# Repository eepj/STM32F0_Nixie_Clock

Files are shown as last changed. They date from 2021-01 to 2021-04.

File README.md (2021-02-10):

# STM32F0_Nixie_Clock
An STM32 nixie clock project.

## Disclaimer
High DC voltages can cause severe injuries or death. Proceed at your own risk.

## Hardware 
### Files
* [KiCad project](./Hardware/STM32F0_Nixie_Clock.pro)
* [Schematics](./Hardware/STM32F0_Nixie_Clock.pdf)
* [Gerber](./main/Hardware/Gerber)

### Parts
Refer to [BOM](./Hardware/STM32F0_Nixie_Clock_BOM.xlsx):
* [STM32F042F6 core](https://www.st.com/resource/en/datasheet/stm32f042f6.pdf)
* [MAX1771 step-up driver](https://datasheets.maximintegrated.com/en/ds/MAX1771.pdf)
* [DS3231 I2C RTC](https://www.maximintegrated.com/en/products/analog/real-time-clocks/DS3231.html)
* [HV5222 32-channel open-drain serial-to-parallel converter](https://ww1.microchip.com/downloads/en/DeviceDoc/20005418B.pdf)

## Firmware
### Programs
* Main program: [`main.c`](./Firmware/Core/Src/main.c)
* Interrupts: [`stm32f0xx_it.c`](/Firmware/Core/Src/stm32f0xx_it.c)

### Custom libraries
* HV5222 driver: [`nixie.h`](./Firmware/Core/Src/lib/sr)
* DS3231 driver: [`ds3231_for_stm32_hal.h`](https://github.com/eepj/ds3231_for_stm32_hal)

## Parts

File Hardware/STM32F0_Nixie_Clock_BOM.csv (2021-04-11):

Designator | Value | Footprint
BT101 | CR2032 3V | Battery:BatteryHolder_Keystone_1060_1x2032
C101 | 2.2u | Capacitor_SMD:C_0603_1608Metric_Pad1.05x0.95mm_HandSolder
C102 | 100n | Capacitor_SMD:C_0603_1608Metric_Pad1.05x0.95mm_HandSolder
C103 | 1u | Capacitor_SMD:C_1206_3216Metric_Pad1.42x1.75mm_HandSolder
C104 | 4.7u | Capacitor_SMD:C_1210_3225Metric_Pad1.42x2.65mm_HandSolder
C105 | 4.7u/400V | Capacitor_SMD:CP_Elec_8x10.5
C106 | 220u/16V | Capacitor_SMD:CP_Elec_6.3x7.7
C107 | 100n | Capacitor_SMD:C_0603_1608Metric_Pad1.05x0.95mm_HandSolder
C108 | 100n | Capacitor_SMD:C_0603_1608Metric_Pad1.05x0.95mm_HandSolder
D101 | ES2J | Diode_SMD:D_SMA_Handsoldering
DS101 | JST PH 2.0mm 11P | Connector_JST:JST_PH_B11B-PH-K_1x11_P2.00mm_Vertical
DS102 | JST PH 2.0mm 11P | Connector_JST:JST_PH_B11B-PH-K_1x11_P2.00mm_Vertical
DS103 | JST PH 2.0mm 11P | Connector_JST:JST_PH_B11B-PH-K_1x11_P2.00mm_Vertical
DS104 | JST PH 2.0mm 11P | Connector_JST:JST_PH_B11B-PH-K_1x11_P2.00mm_Vertical
DS105 | JST PH 2.0mm 11P | Connector_JST:JST_PH_B11B-PH-K_1x11_P2.00mm_Vertical
DS106 | JST PH 2.0mm 11P | Connector_JST:JST_PH_B11B-PH-K_1x11_P2.00mm_Vertical
J101 | USB-C Receptacle | Connector_USB:USB_C_Receptacle_HRO_TYPE-C-31-M-12
L101 | 100u/2.2A | Inductor_SMD:L_12x12mm_H8mm
NE101 | Dot 1 | Connector_JST:JST_PH_B2B-PH-K_1x02_P2.00mm_Vertical
NE102 | Dot 2 | Connector_JST:JST_PH_B2B-PH-K_1x02_P2.00mm_Vertical
NE103 | Dot 3 | Connector_JST:JST_PH_B2B-PH-K_1x02_P2.00mm_Vertical
NE104 | Dot 4 | Connector_JST:JST_PH_B2B-PH-K_1x02_P2.00mm_Vertical
Q101 | IRF740S | Package_TO_SOT_SMD:TO-263-2
R101 | 10k | Resistor_SMD:R_0603_1608Metric_Pad1.05x0.95mm_HandSolder
R102 | 4k7 | Resistor_SMD:R_0603_1608Metric_Pad1.05x0.95mm_HandSolder
R103 | 4k7 | Resistor_SMD:R_0603_1608Metric_Pad1.05x0.95mm_HandSolder
R104 | 10k | Resistor_SMD:R_0603_1608Metric_Pad1.05x0.95mm_HandSolder
R105 | 1M1 | Resistor_SMD:R_0603_1608Metric_Pad1.05x0.95mm_HandSolder
R106 | R050 | Resistor_SMD:R_2512_6332Metric_Pad1.52x3.35mm_HandSolder
R107 | 10k | Resistor_SMD:R_0603_1608Metric_Pad1.05x0.95mm_HandSolder
R108 | 20k | Resistor_SMD:R_0603_1608Metric_Pad1.05x0.95mm_HandSolder
R109 | 20k | Resistor_SMD:R_0603_1608Metric_Pad1.05x0.95mm_HandSolder
R110 | 20k | Resistor_SMD:R_0603_1608Metric_Pad1.05x0.95mm_HandSolder
R111 | 20k | Resistor_SMD:R_0603_1608Metric_Pad1.05x0.95mm_HandSolder
R112 | 20k | Resistor_SMD:R_0603_1608Metric_Pad1.05x0.95mm_HandSolder
R113 | 20k | Resistor_SMD:R_0603_1608Metric_Pad1.05x0.95mm_HandSolder
R114 | 20k | Resistor_SMD:R_0603_1608Metric_Pad1.05x0.95mm_HandSolder
R115 | 20k | Resistor_SMD:R_0603_1608Metric_Pad1.05x0.95mm_HandSolder
R116 | 20k | Resistor_SMD:R_0603_1608Metric_Pad1.05x0.95mm_HandSolder
R117 | 20k | Resistor_SMD:R_0603_1608Metric_Pad1.05x0.95mm_HandSolder
RV101 | 200k | Potentiometer_THT:Potentiometer_Vishay_T73YP_Vertical
SW101 | TL3342 | Button_Switch_SMD:SW_SPST_TL3342
U101 | STM32F042F6P6 | Package_SO:TSSOP-20_4.4x6.5mm_P0.65mm
U102 | AMS1117-3.3 | Package_TO_SOT_SMD:SOT-223-3_TabPin2
U103 | DS3231M | Package_SO:SOIC-16W_7.5x10.3mm_P1.27mm
U104 | MAX1771 | Package_SO:SO-8_3.9x4.9mm_P1.27mm
U105 | HV5222PLCC | Package_LCC:PLCC-44_16.6x16.6mm_P1.27mm
U106 | HV5222PLCC | Package_LCC:PLCC-44_16.6x16.6mm_P1.27mm

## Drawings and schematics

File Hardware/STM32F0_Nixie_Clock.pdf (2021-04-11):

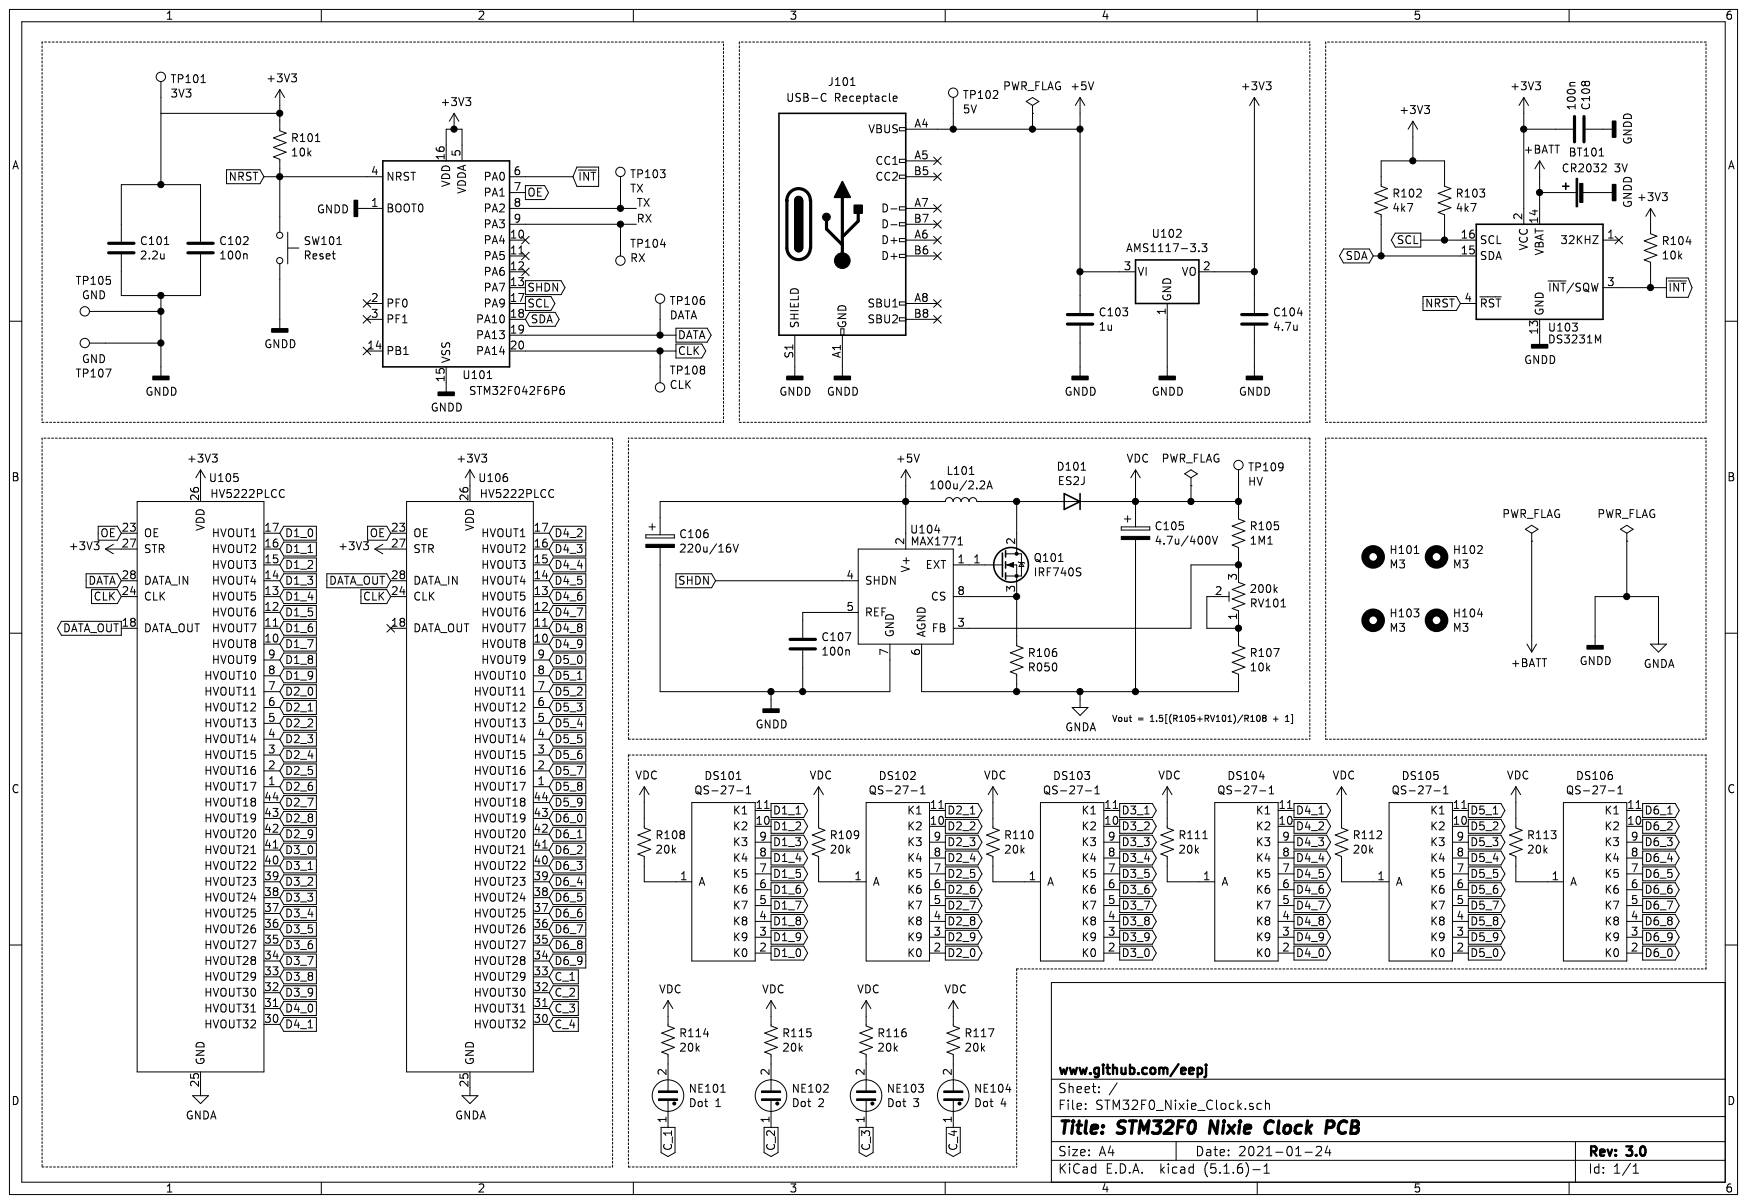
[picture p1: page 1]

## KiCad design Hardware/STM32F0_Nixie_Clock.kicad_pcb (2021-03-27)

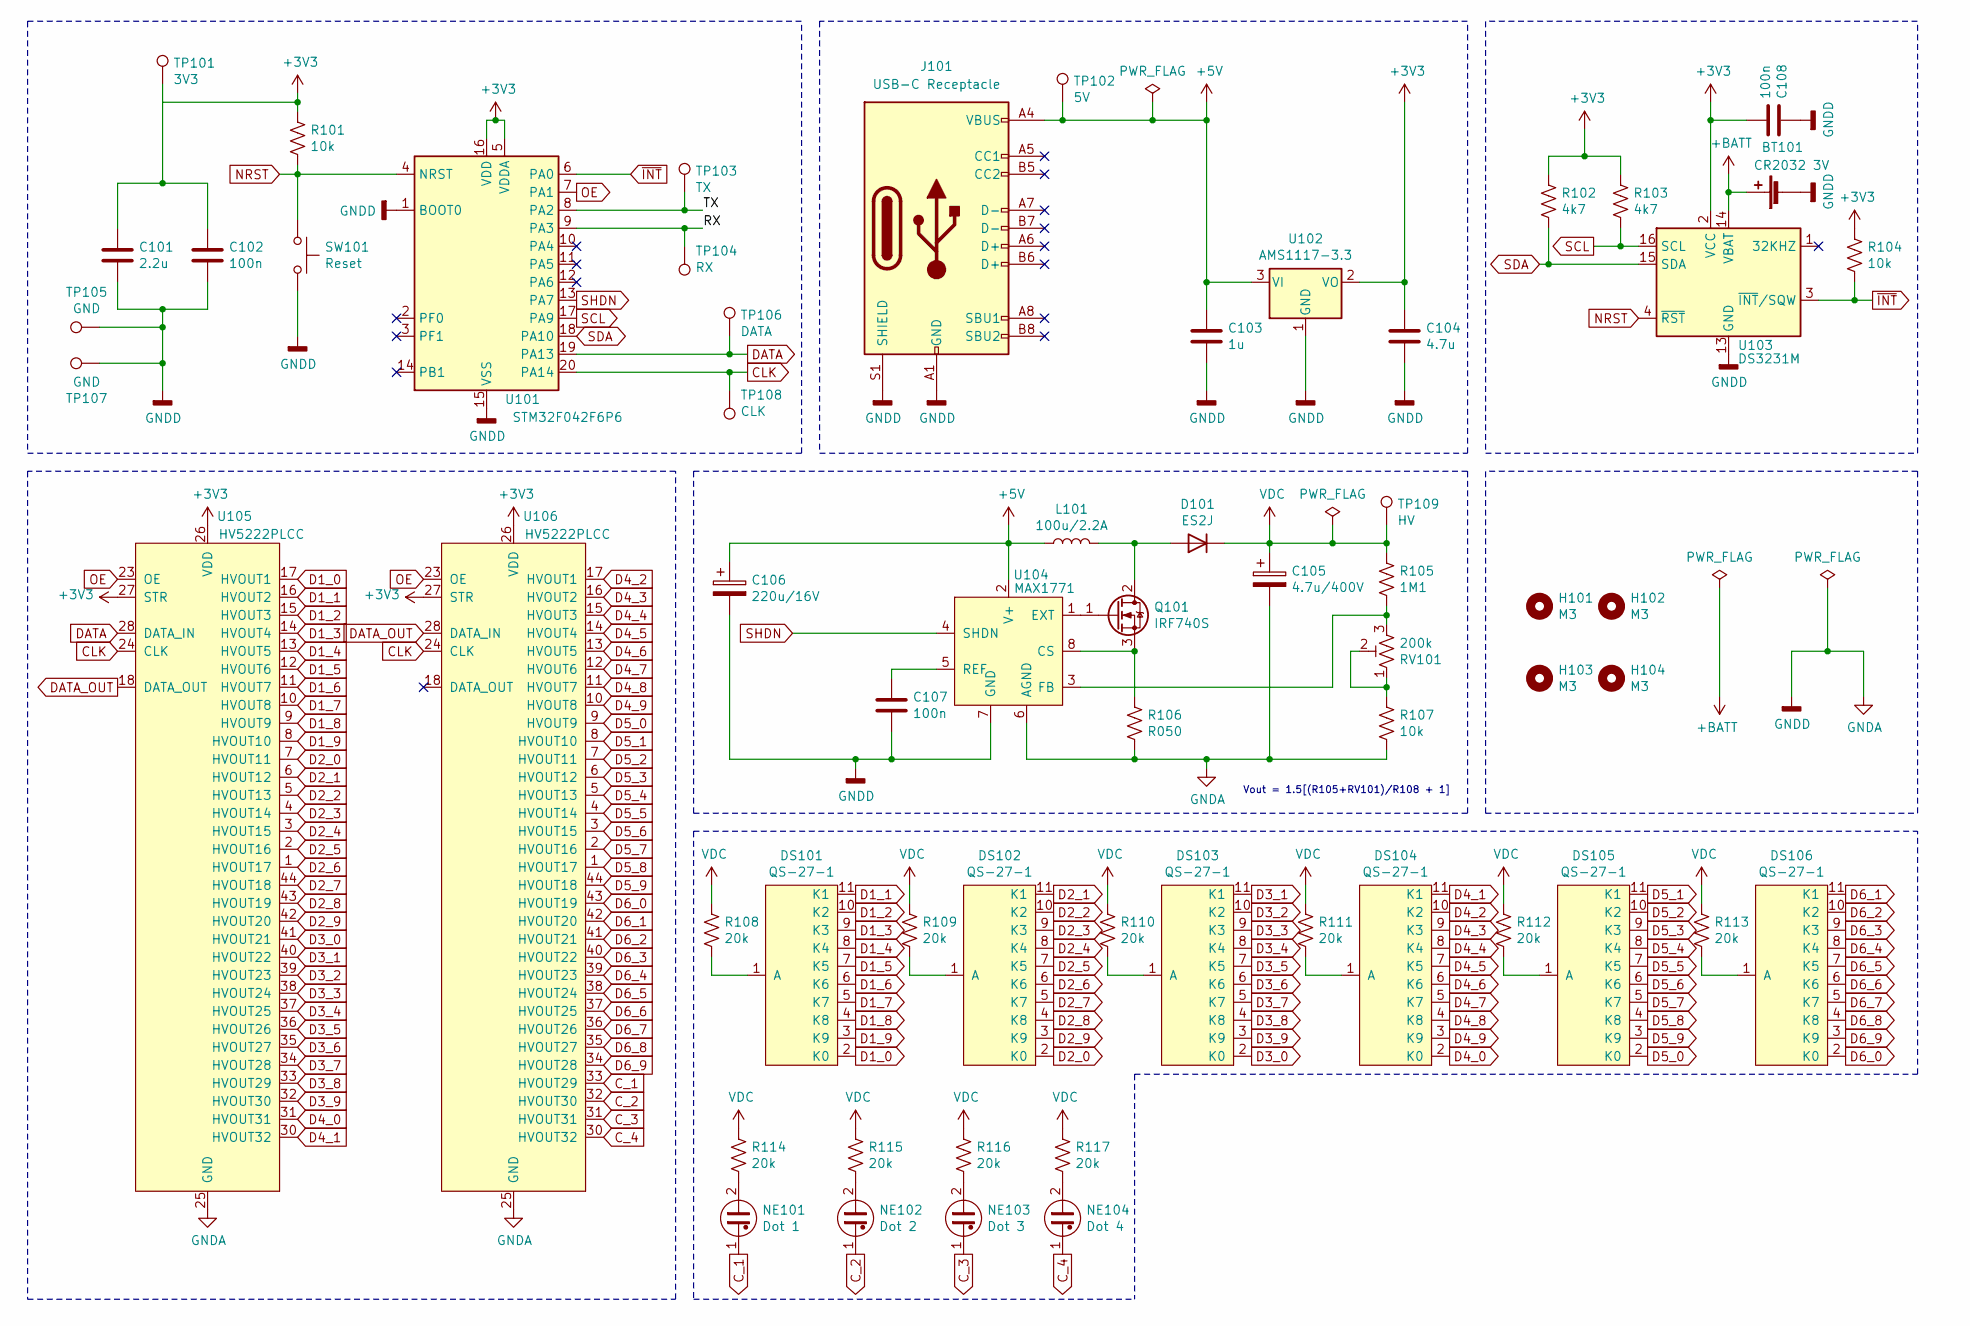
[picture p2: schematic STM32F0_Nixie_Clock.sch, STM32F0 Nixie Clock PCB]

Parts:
BT101: CR2032 3V; BatteryHolder_Keystone_1060_1x2032
C101: 2.2u; C_0603_1608Metric_Pad1.05x0.95mm_HandSolder
C102, C107, C108: 100n; C_0603_1608Metric_Pad1.05x0.95mm_HandSolder
C103: 1u; C_1206_3216Metric_Pad1.42x1.75mm_HandSolder
C104: 4.7u; C_1210_3225Metric_Pad1.42x2.65mm_HandSolder
C105: 4.7u/400V; CP_Elec_8x10.5
C106: 220u/16V; CP_Elec_6.3x7.7
D101: ES2J; D_SMA_Handsoldering
DS101, DS102, DS103, DS104, DS105, DS106: QS-27-1; JST_PH_B11B-PH-K_1x11_P2.00mm_Vertical
H101, H102, H103, H104: M3; MountingHole_3.2mm_M3
J101: USB-C Receptacle; USB_C_Receptacle_HRO_TYPE-C-31-M-12
L101: 100u/2.2A; L_12x12mm_H8mm
NE101: Dot 1; JST_PH_B2B-PH-K_1x02_P2.00mm_Vertical
NE102: Dot 2; JST_PH_B2B-PH-K_1x02_P2.00mm_Vertical
NE103: Dot 3; JST_PH_B2B-PH-K_1x02_P2.00mm_Vertical
NE104: Dot 4; JST_PH_B2B-PH-K_1x02_P2.00mm_Vertical
Q101: IRF740S; TO-263-2
R101, R104, R107: 10k; R_0603_1608Metric_Pad1.05x0.95mm_HandSolder
R102, R103: 4k7; R_0603_1608Metric_Pad1.05x0.95mm_HandSolder
R105: 1M1; R_0603_1608Metric_Pad1.05x0.95mm_HandSolder
R106: R050; R_2512_6332Metric_Pad1.52x3.35mm_HandSolder
R108, R109, R110, R111, R112, R113, R114, R115, R116, R117: 20k; R_0603_1608Metric_Pad1.05x0.95mm_HandSolder
RV101: 200k; Potentiometer_Vishay_T73YP_Vertical
SW101: Reset; SW_SPST_TL3342
TP101: 3V3; TestPoint_Pad_D1.5mm
TP102: 5V; TestPoint_Pad_D1.5mm
TP103: TX; TestPoint_Pad_D1.5mm
TP104: RX; TestPoint_Pad_D1.5mm
TP105, TP107: GND; TestPoint_Pad_D1.5mm
TP106: DATA; TestPoint_Pad_D1.5mm
TP108: CLK; TestPoint_Pad_D1.5mm
TP109: HV; TestPoint_Pad_1.0x1.0mm
U101: STM32F042F6P6; TSSOP-20_4.4x6.5mm_P0.65mm
U102: AMS1117-3.3; SOT-223-3_TabPin2
U103: DS3231M; SOIC-16W_7.5x10.3mm_P1.27mm
U104: MAX1771; SO-8_3.9x4.9mm_P1.27mm
U105, U106: HV5222PLCC; PLCC-44_16.6x16.6mm_P1.27mm

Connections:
+3V3: C101.1, C102.1, C104.1, C108.2, R101.1, R102.1, R103.1, R104.1, TP101.1, U101.5 (VDDA), U101.16 (VDD), U102.2 (VO), U103.2 (VCC), U105.26 (VDD), U105.27 (STR), U106.26 (VDD), U106.27 (STR)
+5V: C103.1, C106.1, J101.A4 (VBUS), J101.A9 (VBUS), J101.B4 (VBUS), J101.B9 (VBUS), L101.1, TP102.1, U102.3 (VI), U104.2 (V+)
+BATT: BT101.1 (+), U103.14 (VBAT)
/RX: TP104.1, U101.9 (PA3)
/TX: TP103.1, U101.8 (PA2)
CLK: TP108.1, U101.20 (PA14), U105.24 (CLK), U106.24 (CLK)
C_1: NE101.1, U106.33 (HVOUT29)
C_2: NE102.1, U106.32 (HVOUT30)
C_3: NE103.1, U106.31 (HVOUT31)
C_4: NE104.1, U106.30 (HVOUT32)
D1_0: DS101.2 (K0), U105.17 (HVOUT1)
D1_1: DS101.11 (K1), U105.16 (HVOUT2)
D1_2: DS101.10 (K2), U105.15 (HVOUT3)
D1_3: DS101.9 (K3), U105.14 (HVOUT4)
D1_4: DS101.8 (K4), U105.13 (HVOUT5)
D1_5: DS101.7 (K5), U105.12 (HVOUT6)
D1_6: DS101.6 (K6), U105.11 (HVOUT7)
D1_7: DS101.5 (K7), U105.10 (HVOUT8)
D1_8: DS101.4 (K8), U105.9 (HVOUT9)
D1_9: DS101.3 (K9), U105.8 (HVOUT10)
D2_0: DS102.2 (K0), U105.7 (HVOUT11)
D2_1: DS102.11 (K1), U105.6 (HVOUT12)
D2_2: DS102.10 (K2), U105.5 (HVOUT13)
D2_3: DS102.9 (K3), U105.4 (HVOUT14)
D2_4: DS102.8 (K4), U105.3 (HVOUT15)
D2_5: DS102.7 (K5), U105.2 (HVOUT16)
D2_6: DS102.6 (K6), U105.1 (HVOUT17)
D2_7: DS102.5 (K7), U105.44 (HVOUT18)
D2_8: DS102.4 (K8), U105.43 (HVOUT19)
D2_9: DS102.3 (K9), U105.42 (HVOUT20)
D3_0: DS103.2 (K0), U105.41 (HVOUT21)
D3_1: DS103.11 (K1), U105.40 (HVOUT22)
D3_2: DS103.10 (K2), U105.39 (HVOUT23)
D3_3: DS103.9 (K3), U105.38 (HVOUT24)
D3_4: DS103.8 (K4), U105.37 (HVOUT25)
D3_5: DS103.7 (K5), U105.36 (HVOUT26)
D3_6: DS103.6 (K6), U105.35 (HVOUT27)
D3_7: DS103.5 (K7), U105.34 (HVOUT28)
D3_8: DS103.4 (K8), U105.33 (HVOUT29)
D3_9: DS103.3 (K9), U105.32 (HVOUT30)
D4_0: DS104.2 (K0), U105.31 (HVOUT31)
D4_1: DS104.11 (K1), U105.30 (HVOUT32)
D4_2: DS104.10 (K2), U106.17 (HVOUT1)
D4_3: DS104.9 (K3), U106.16 (HVOUT2)
D4_4: DS104.8 (K4), U106.15 (HVOUT3)
D4_5: DS104.7 (K5), U106.14 (HVOUT4)
D4_6: DS104.6 (K6), U106.13 (HVOUT5)
D4_7: DS104.5 (K7), U106.12 (HVOUT6)
D4_8: DS104.4 (K8), U106.11 (HVOUT7)
D4_9: DS104.3 (K9), U106.10 (HVOUT8)
D5_0: DS105.2 (K0), U106.9 (HVOUT9)
D5_1: DS105.11 (K1), U106.8 (HVOUT10)
D5_2: DS105.10 (K2), U106.7 (HVOUT11)
D5_3: DS105.9 (K3), U106.6 (HVOUT12)
D5_4: DS105.8 (K4), U106.5 (HVOUT13)
D5_5: DS105.7 (K5), U106.4 (HVOUT14)
D5_6: DS105.6 (K6), U106.3 (HVOUT15)
D5_7: DS105.5 (K7), U106.2 (HVOUT16)
D5_8: DS105.4 (K8), U106.1 (HVOUT17)
D5_9: DS105.3 (K9), U106.44 (HVOUT18)
D6_0: DS106.2 (K0), U106.43 (HVOUT19)
D6_1: DS106.11 (K1), U106.42 (HVOUT20)
D6_2: DS106.10 (K2), U106.41 (HVOUT21)
D6_3: DS106.9 (K3), U106.40 (HVOUT22)
D6_4: DS106.8 (K4), U106.39 (HVOUT23)
D6_5: DS106.7 (K5), U106.38 (HVOUT24)
D6_6: DS106.6 (K6), U106.37 (HVOUT25)
D6_7: DS106.5 (K7), U106.36 (HVOUT26)
D6_8: DS106.4 (K8), U106.35 (HVOUT27)
D6_9: DS106.3 (K9), U106.34 (HVOUT28)
DATA: TP106.1, U101.19 (PA13), U105.28 (DATA_IN)
DATA_OUT: U105.18 (DATA_OUT), U106.28 (DATA_IN)
GNDA: BT101.2 (-), C101.2, C102.2, C103.2, C104.2, C105.2, C106.2, C107.2, C108.1, J101.A1 (GND), J101.A12 (GND), J101.B1 (GND), J101.B12 (GND), J101.S1 (SHIELD), R106.2, R107.2, SW101.2, TP105.1, TP107.1, U101.1 (BOOT0), U101.15 (VSS), U102.1 (GND), U103.5 (GND), U103.6 (GND), U103.7 (GND), U103.8 (GND), U103.9 (GND), U103.10 (GND), U103.11 (GND), U103.12 (GND), U103.13 (GND), U104.6 (AGND), U104.7 (GND), U105.25 (GND), U106.25 (GND)
NRST: R101.2, SW101.1, U101.4 (NRST), U103.4 (~RST)
unnamed: C107.1, U104.5 (REF)
unnamed: D101.2 (A), L101.2, Q101.2 (D)
unnamed: DS101.1 (A), R108.2
unnamed: DS102.1 (A), R109.2
unnamed: DS103.1 (A), R110.2
unnamed: DS104.1 (A), R111.2
unnamed: DS105.1 (A), R112.2
unnamed: DS106.1 (A), R113.2
unnamed: NE101.2, R114.2
unnamed: NE102.2, R115.2
unnamed: NE103.2, R116.2
unnamed: NE104.2, R117.2
unnamed: Q101.1 (G), U104.1 (EXT)
unnamed: Q101.3 (S), R106.1, U104.8 (CS)
unnamed: R105.2, RV101.3, U104.3 (FB)
unnamed: R107.1, RV101.1, RV101.2
OE: U101.7 (PA1), U105.23 (OE), U106.23 (OE)
SCL: R103.2, U101.17 (PA9), U103.16 (SCL)
SDA: R102.2, U101.18 (PA10), U103.15 (SDA)
SHDN: U101.13 (PA7), U104.4 (SHDN)
VDC: C105.1, D101.1 (K), R105.1, R108.1, R109.1, R110.1, R111.1, R112.1, R113.1, R114.1, R115.1, R116.1, R117.1, TP109.1
~INT: R104.2, U101.6 (PA0), U103.3 (~INT~/SQW)

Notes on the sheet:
Vout = 1.5[(R105+RV101)/R108 + 1]

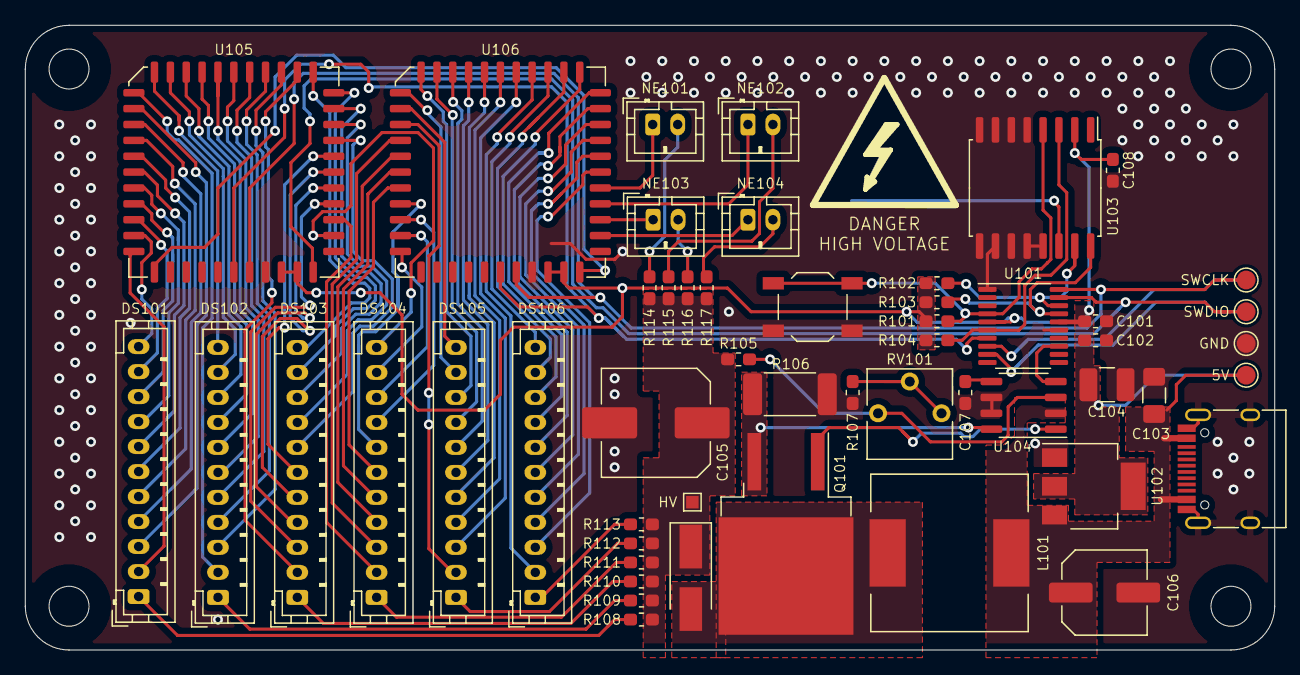
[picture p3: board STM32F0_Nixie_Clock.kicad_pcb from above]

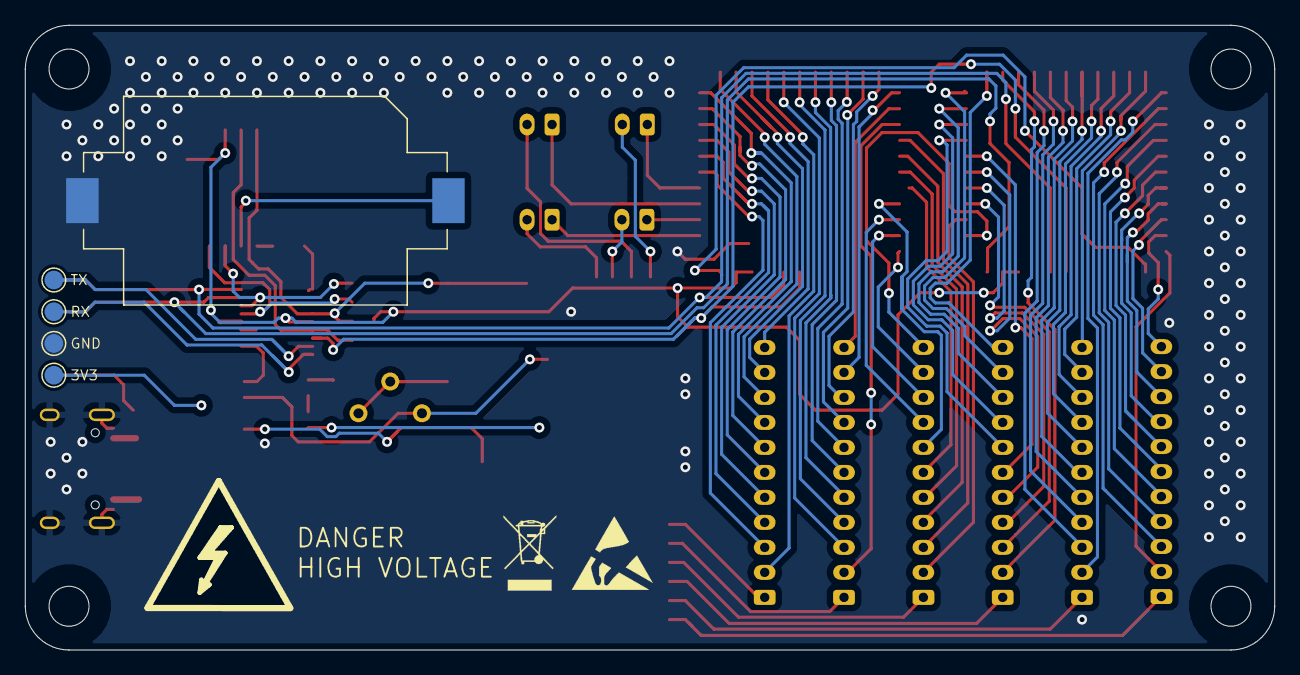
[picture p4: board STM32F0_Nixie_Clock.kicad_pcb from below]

Board: 2 copper layers, 100.0 x 50.0 mm, 61 parts (5 on the bottom side), 96 nets.

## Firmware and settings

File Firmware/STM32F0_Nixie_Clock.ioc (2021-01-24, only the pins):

Mcu.UserName=STM32F042F6Px
PA0.GPIO_Label=INT
PA0.Signal=GPXTI0
PA1.GPIO_Label=OE
PA1.Signal=GPIO_Output
PA10.Signal=I2C1_SDA
PA13.GPIO_Label=DATA
PA13.Signal=GPIO_Output
PA14.GPIO_Label=CLK
PA14.Signal=GPIO_Output
PA2.Signal=USART2_TX
PA3.Signal=USART2_RX
PA7.GPIO_Label=SHDN
PA7.Signal=GPIO_Output
PA9.Signal=I2C1_SCL

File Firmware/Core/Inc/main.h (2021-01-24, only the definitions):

#define INT_Pin GPIO_PIN_0
#define INT_GPIO_Port GPIOA
#define INT_EXTI_IRQn EXTI0_1_IRQn
#define OE_Pin GPIO_PIN_1
#define OE_GPIO_Port GPIOA
#define SHDN_Pin GPIO_PIN_7
#define SHDN_GPIO_Port GPIOA
#define DATA_Pin GPIO_PIN_13
#define DATA_GPIO_Port GPIOA
#define CLK_Pin GPIO_PIN_14
#define CLK_GPIO_Port GPIOA

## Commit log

2021-01-24 Add STM32CubeMX project
2021-01-24 Add pin assignment and configuration
2021-01-24 Modify pin assignment
2021-01-24 Import version 3.0 PCB KiCad project
    [STM32F0_Nixie_Clock.kicad_pcb, STM32F0_Nixie_Clock.sch, STM32F0_Nixie_Clock_BOM.xlsx]
2021-01-24 Update schematics PDF
2021-01-26 Clean up brackets
2021-01-29 Add decoupling decapacitor to RTC
    [STM32F0_Nixie_Clock.kicad_pcb, STM32F0_Nixie_Clock.sch]
2021-01-29 Plot gerber
    [STM32F0_Nixie_Clock-B_Cu.gbr, STM32F0_Nixie_Clock-B_Mask.gbr, STM32F0_Nixie_Clock-B_Paste.gbr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]
2021-03-27 Replace USB-C receptacle symbol
    [STM32F0_Nixie_Clock.kicad_pcb, STM32F0_Nixie_Clock.sch]
2021-04-11 Repository restructure
    [STM32F0_Nixie_Clock-B_Cu.gbr, STM32F0_Nixie_Clock-B_Mask.gbr, STM32F0_Nixie_Clock-B_Paste.gbr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]
2021-04-11 Resturcture repository
    [STM32F0_Nixie_Clock-B_Cu.gbr, STM32F0_Nixie_Clock-B_Mask.gbr, STM32F0_Nixie_Clock-B_Paste.gbr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]

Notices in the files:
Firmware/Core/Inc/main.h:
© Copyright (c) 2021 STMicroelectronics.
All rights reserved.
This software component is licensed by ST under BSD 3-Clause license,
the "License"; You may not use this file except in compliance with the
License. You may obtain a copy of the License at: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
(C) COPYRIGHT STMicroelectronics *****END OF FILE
